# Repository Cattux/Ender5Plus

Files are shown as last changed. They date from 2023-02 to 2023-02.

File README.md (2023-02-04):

# Ender 5 Plus
This repo contains the modifications and current configuration files for my Creality Ender 5 Plus.

## Main Board
The main board in this printer is an BTT Octopus Pro (F446).

## Screen
The screen is still the stock screen. A custom cable was created so that it could work with the new main board via the TFT pins, see pinout below:

| LCD Pin | SKR Pin | Description |
| --- | :-- | :-- |
| 1 | 5 | 5V | 
| 2 | NC | | 
| 3 | 3 |  LCD RX / SKR TX2  | 
| 4 | 2 | LCD TX / SKR RX2 | 
| 5 | NC | | 
| 6 | 4 | GND | 

Photos of cable are available here: https://imgur.com/a/O3nix8B

## Extruder
Stock

## Bed Heater
Stock

## Build Plate
Stock

## BLTouch
Stock

## Part Cooler
Stock

## Hotend Cooler
Stock cooler, but klipper has been configured so that the fan only turns on when the temperature is set to 50°C or above. When the hot end turns off, the fan turns off once the temperature drops back below 50°C.

## Enclosure Fan
The stock enclosure fan was always on and very loud, so it was replaced with a 5V Noctua fan. It is connected to the Octopus via one of the fan ports which is set to 5V. It turns on and off automatically whenever the extruder or bed are turned on.

## Firmware
Klipper is loaded onto this printer, see [printer.cfg](printer.cfg)

It is running on a Raspberry Pi 4B mounted inside the control box using the [3D printed mount found here](Ender5Plus-Octopus-and-Pi-Mount.stl).

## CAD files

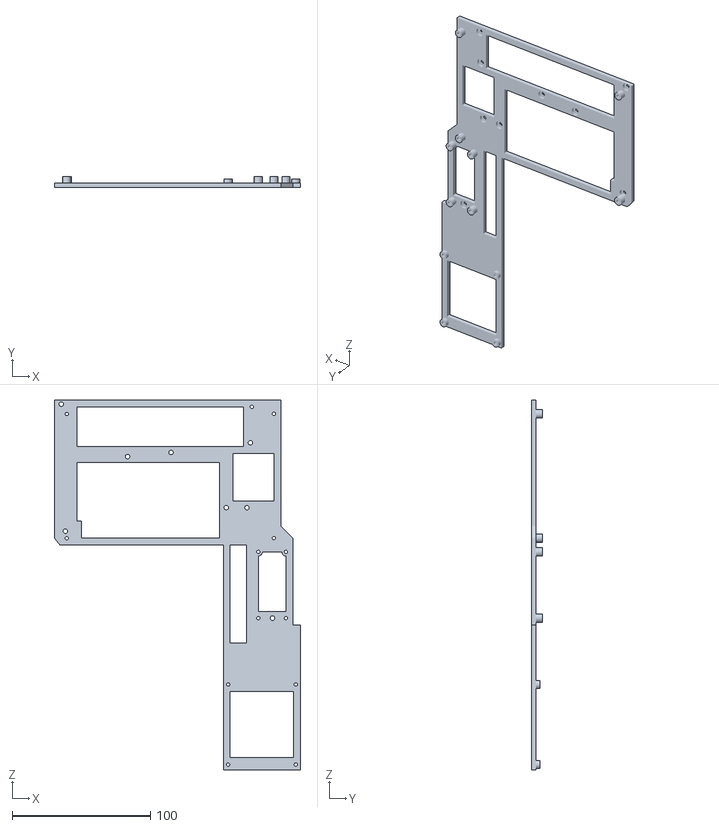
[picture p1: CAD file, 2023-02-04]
Ender5Plus-Octopus-and-Pi-Mount.stl
178.3 x 8.00 x 268.0

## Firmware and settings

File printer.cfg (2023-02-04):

# This file contains common pin mappings for the BigTreeTech Octopus
# and Octopus Pro boards. To use this config, start by identifying the
# micro-controller on the board - it may be an STM32F446, STM32F429,
# or an STM32H723.  Select the appropriate micro-controller in "make
# menuconfig" and select "Enable low-level configuration options". For
# STM32F446 boards the firmware should be compiled with a "32KiB
# bootloader" and a "12MHz crystal" clock reference. For STM32F429
# boards use a "32KiB bootloader" and an "8MHz crystal". For STM32H723
# boards use a "128KiB bootloader" and a "25Mhz crystal".

# The "make flash" command does not work on the Octopus Pro when wired to a Pi
# via UART. Instead, after running "make", copy the generated "out/klipper.bin" 
# file to a file named "firmware.bin" on an SD card and then restart the Octopus
# Pro with that SD card.

# See docs/Config_Reference.md for a description of parameters.

[temperature_sensor raspberry_pi]
sensor_type: temperature_host
min_temp: 10
max_temp: 100

# [temperature_sensor mcu_temp]
# sensor_type: temperature_mcu
# min_temp: 0
# max_temp: 100

[stepper_x]
step_pin: PF13
dir_pin: !PF12
enable_pin: !PF14
microsteps: 16
rotation_distance: 40
endstop_pin: ^PG6
position_endstop: 360
position_max: 360
homing_speed: 100

[tmc2208 stepper_x]
uart_pin: PC4
run_current: 0.580
hold_current: 0.500
stealthchop_threshold: 999999

[stepper_y]
step_pin: PG0
dir_pin: !PG1
enable_pin: !PF15
microsteps: 16
rotation_distance: 40
endstop_pin: ^PG9
position_endstop: 350
position_max: 350
homing_speed: 100

[tmc2208 stepper_y]
uart_pin: PD11
run_current: 0.580
hold_current: 0.500
stealthchop_threshold: 999999

[stepper_z]
step_pin: PF11
dir_pin: !PG3
enable_pin: !PG5
microsteps: 16
rotation_distance: 4
endstop_pin: probe:z_virtual_endstop
position_max: 410
position_min: -4
homing_speed: 10.0

[tmc2208 stepper_z]
uart_pin: PC6
run_current: 0.580
hold_current: 0.500
stealthchop_threshold: 999999

[stepper_z1]
step_pin: PG4
dir_pin: !PC1
enable_pin: !PA0
microsteps: 16
rotation_distance: 4

[tmc2208 stepper_z1]
uart_pin: PC7
run_current: 0.580
hold_current: 0.500
stealthchop_threshold: 999999

[safe_z_home]
home_xy_position: 220, 180
speed: 100
z_hop: 10
z_hop_speed: 5

[bltouch]
sensor_pin: ^PG10
control_pin: PB0
x_offset: -47.5
y_offset: -10
#z_offset: 0
speed: 2.0
samples: 2
sample_retract_dist: 4.0
probe_with_touch_mode: True

[bed_mesh]
speed: 100
horizontal_move_z: 8
mesh_min: 50, 50
mesh_max: 300,300
probe_count: 3,3

[z_tilt]
z_positions: 380, 180
             -35, 180
points: 360, 180
         75, 180
retries: 10
retry_tolerance: 0.001

[extruder]
step_pin: PC13
dir_pin: !PF0
enable_pin: !PF1
microsteps: 16
rotation_distance: 33.0
nozzle_diameter: 0.400
filament_diameter: 1.750
heater_pin: PA3
sensor_type: EPCOS 100K B57560G104F
sensor_pin: PF4
#control: pid
#pid_Kp: 22.2
#pid_Ki: 1.08
#pid_Kd: 114
min_extrude_temp: 175 ; override this value with 0 if debugging the extruder without being connected to the hotend
min_temp: 0
max_temp: 260

[tmc2208 extruder]
uart_pin: PE4
run_current: 0.650
hold_current: 0.500
stealthchop_threshold: 999999 #5

[filament_switch_sensor filament_sensor]
switch_pin: PG12

[heater_bed]
heater_pin: PA1
sensor_type: ATC Semitec 104GT-2
sensor_pin: PF3
#control: pid
#pid_Kp: 690.34
#pid_Ki: 111.47
#pid_Kd: 1068.83
min_temp: 0
max_temp: 130

[gcode_macro G29]
gcode: 
  G28
  BED_MESH_CALIBRATE
  BED_MESH_PROFILE SAVE=p1
  G1 X0 Y0 Z5 F4000

[heater_fan nozzle_cooling_fan] #fan0
pin: PD12
heater_temp: 50.0
heater: extruder

[controller_fan control_box] #fan1
pin: PE5
heater: heater_bed

[fan] #fan2
pin: PA8

# Stock Ender 5 Plus display with custom firmware
[t5uid1]
firmware: dgus_reloaded #this section is required to use stock ender 5 plus screen with klipper

[mcu]
serial: /dev/ttyAMA0
restart_method: command
baud: 250000

[printer]
kinematics: cartesian
max_velocity: 300
max_accel: 3000
max_z_velocity: 5
max_z_accel: 100

[virtual_sdcard]
path: ~/gcode_files

[input_shaper]
#shaper_freq_x: 36.81 #uncomment to enter input shaper x frequency
#shaper_freq_y: 38.31 #uncomment to enter input shaper y frequency
#shaper_type: mzv #uncomment to enter input shaper type

[board_pins]
aliases:
    # EXP1 header
    EXP1_1=PE8, EXP1_2=PE7,
    EXP1_3=PE9, EXP1_4=PE10,
    EXP1_5=PE12, EXP1_6=PE13,    # Slot in the socket on this side
    EXP1_7=PE14, EXP1_8=PE15,
    EXP1_9=<GND>, EXP1_10=<5V>,

    # EXP2 header
    EXP2_1=PA6, EXP2_2=PA5,
    EXP2_3=PB1, EXP2_4=PA4,
    EXP2_5=PB2, EXP2_6=PA7,      # Slot in the socket on this side
    EXP2_7=PC15, EXP2_8=<RST>,
    EXP2_9=<GND>, EXP2_10=PC5
    
[display_status]

[pause_resume]

[gcode_macro PAUSE]
rename_existing: BASE_PAUSE
#default_parameter_E: 1.7

gcode:
  {% set E = params.E|default(1.7)|float %}
  {% set x_park = printer.toolhead.axis_maximum.x|float - 5.0 %}
  {% set y_park = printer.toolhead.axis_maximum.y|float - 5.0 %}
  {% set max_z = printer.toolhead.axis_maximum.z|float %}
  {% set act_z = printer.toolhead.position.z|float %}
  {% if act_z < (max_z - 2.0) %}
      {% set z_safe = 2.0 %}
  {% else %}
      {% set z_safe = max_z - act_z %}
  {% endif %}
  SAVE_GCODE_STATE NAME=PAUSE_state
  BASE_PAUSE
  G91
  G1 E-{E} F2100
  G1 Z{z_safe} F900
  G90
  G0 X{x_park} Y{y_park} F6000
  G91

[gcode_macro RESUME]
rename_existing: BASE_RESUME
#default_parameter_E: 1      # edit to your preferred retract length

gcode:
    {% set E = params.E|default(1)|float %}
    G91
    G1 E{E} F2100
    G90
    RESTORE_GCODE_STATE NAME=PAUSE_state MOVE=1
    BASE_RESUME
    
[gcode_macro CANCEL_PRINT]
rename_existing: BASE_CANCEL_PRINT
gcode:
    TURN_OFF_HEATERS
    CLEAR_PAUSE
    SDCARD_RESET_FILE
    BASE_CANCEL_PRINT

[gcode_macro START_PRINT]
gcode:
    M201 X500.00 Y500.00 Z100.00 E5000.00 ;Setup machine max acceleration
    M203 X500.00 Y500.00 Z10.00 E50.00 ;Setup machine max feedrate
    M204 P500.00 R1000.00 T500.00 ;Setup Print/Retract/Travel acceleration
    M205 X8.00 Y8.00 Z0.40 E5.00 ;Setup Jerk
    M220 S100 ;Reset Feedrate
    M221 S100 ;Reset Flowrate

    G28 ;Home
    
    G92 E0 ;Reset Extruder
    G1 Z2.0 F3000 ;Move Z Axis up
    G1 X10.1 Y20 Z0.28 F5000.0 ;Move to start position
    G1 X10.1 Y200.0 Z0.28 F1500.0 E15 ;Draw the first line
    G1 X10.4 Y200.0 Z0.28 F5000.0 ;Move to side a little
    G1 X10.4 Y20 Z0.28 F1500.0 E30 ;Draw the second line
    G92 E0 ;Reset Extruder
    G1 Z2.0 F3000 ;Move Z Axis up

[gcode_macro END_PRINT]
gcode:
    G91 ;Relative positioning
    G1 E-2 F2700 ;Retract a bit
    G1 E-2 Z0.2 F2400 ;Retract and raise Z
    G1 X5 Y5 F3000 ;Wipe out
    G1 Z10 ;Raise Z more
    G90 ;Absolute positioning

    G1 X340 Y340 ;Present print
    M106 S0 ;Turn-off fan
    M104 S0 ;Turn-off hotend
    M140 S0 ;Turn-off bed

    M84 X Y E ;Disable all steppers but Z

[gcode_macro SHAPE_FILAMENT_END]
gcode:
    G92 E0

    G90 ; move to absolute mode
    M82 ; turn absolute distances for the extruder
    
    G0 E-50 F2000 ; quickly retract the filament to shape it
    G0 E-80 F600 ; slowly allow it to cool

    G0 E1 F2000 ; blob elimination

    G0 E-50 F2000 ; quickly retract the filament to shape it
    G0 E-80 F600; slowly allow it to cool

    G0 E1 F2000 ; blob elimination
    G0 E-10 F2000 ; quickly retract the filament to shape it
    G0 E1 F2000 ; quickly ram the filament to shape it
    G0 E-10 F2000 ; quickly retract the filament to shape it
    G0 E1 F2000 ; quickly ram the filament to shape it

    G0 E-50 F2000 ; quickly retract the filament to shape it
    G0 E-80 F100 ; slowly allow it to cool

    M107 ; this printer has the fan in the way, so turn it off

    G92 E0
    G0 E-100 F2000
    G92 E0
    G0 E-50 F2000
    G92 E0
    G0 E-30 ;
    G92 E0

    G91 ; move to relative mode

# See the sample-lcd.cfg file for definitions of common LCD displays.

#*# <---------------------- SAVE_CONFIG ---------------------->
#*# DO NOT EDIT THIS BLOCK OR BELOW. The contents are auto-generated.
#*#
#*# [bltouch]
#*# z_offset = 2.825
#*#
#*# [bed_mesh default]
#*# version = 1
#*# points =
#*# 	-0.118125, -0.047500, -0.131875
#*# 	-0.088750, 0.020000, -0.168750
#*# 	-0.216875, -0.180000, -0.219375
#*# tension = 0.2
#*# min_x = 50.0
#*# algo = lagrange
#*# y_count = 3
#*# mesh_y_pps = 2
#*# min_y = 50.0
#*# x_count = 3
#*# max_y = 300.0
#*# mesh_x_pps = 2
#*# max_x = 300.0
#*#
#*# [heater_bed]
#*# control = pid
#*# pid_kp = 69.815
#*# pid_ki = 0.774
#*# pid_kd = 1573.449
#*#
#*# [t5uid1]
#*# brightness = 100
#*# volume = 100
#*#
#*# [extruder]
#*# control = pid
#*# pid_kp = 31.598
#*# pid_ki = 2.701
#*# pid_kd = 92.426
#*#
#*# [bed_mesh 60C]
#*# version = 1
#*# points =
#*# 	-0.118125, -0.047500, -0.131875
#*# 	-0.088750, 0.020000, -0.168750
#*# 	-0.216875, -0.180000, -0.219375
#*# tension = 0.2
#*# min_x = 50.0
#*# algo = lagrange
#*# y_count = 3
#*# mesh_y_pps = 2
#*# min_y = 50.0
#*# x_count = 3
#*# max_y = 300.0
#*# mesh_x_pps = 2
#*# max_x = 300.0

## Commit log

2021-12-27 added klipper config files
    [printer.cfg]
2023-02-04 Updated repo for new Octopus main board. - Update printer.cfg - Added STL for board mount - Updated Readme to note configuration changes
    [Ender5Plus-Octopus-and-Pi-Mount.stl, printer.cfg]
